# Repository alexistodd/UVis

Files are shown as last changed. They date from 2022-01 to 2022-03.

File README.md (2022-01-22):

# UV Shield 
## README

UV Shield is a handheld component that allows users to see incoming UV rays on their skin. 
The purpose of the component is to assist users with applying UV protection before going outdoors.

## OPERATION PROCEDURES
To operate the UV Shield component follow these step by step instructions:
1. Press the power button
2. Device should automatically boot up and display the UV Shield logo.
3. After the logo, UV Shield should bootup to display the camera feed.
4. Use the second button to toggle the UV LEDs when indoors.
5. Press the power button to initiate the shutdown process to safely shutdown the UV Shield.

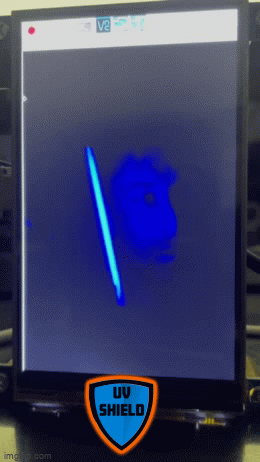
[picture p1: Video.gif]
screen-gif


## CONTACT

stevenamberman@ufl.edu

## GIT

The github repository for this project can be found at:
  https://github.com/alexistodd/UVis

## DISCLAIMER

UVis does not guarentee your safety from harmful UV rays when going outside. This component will assist you with sunscreen application,
but it does not guarentee safety from UV radiation.

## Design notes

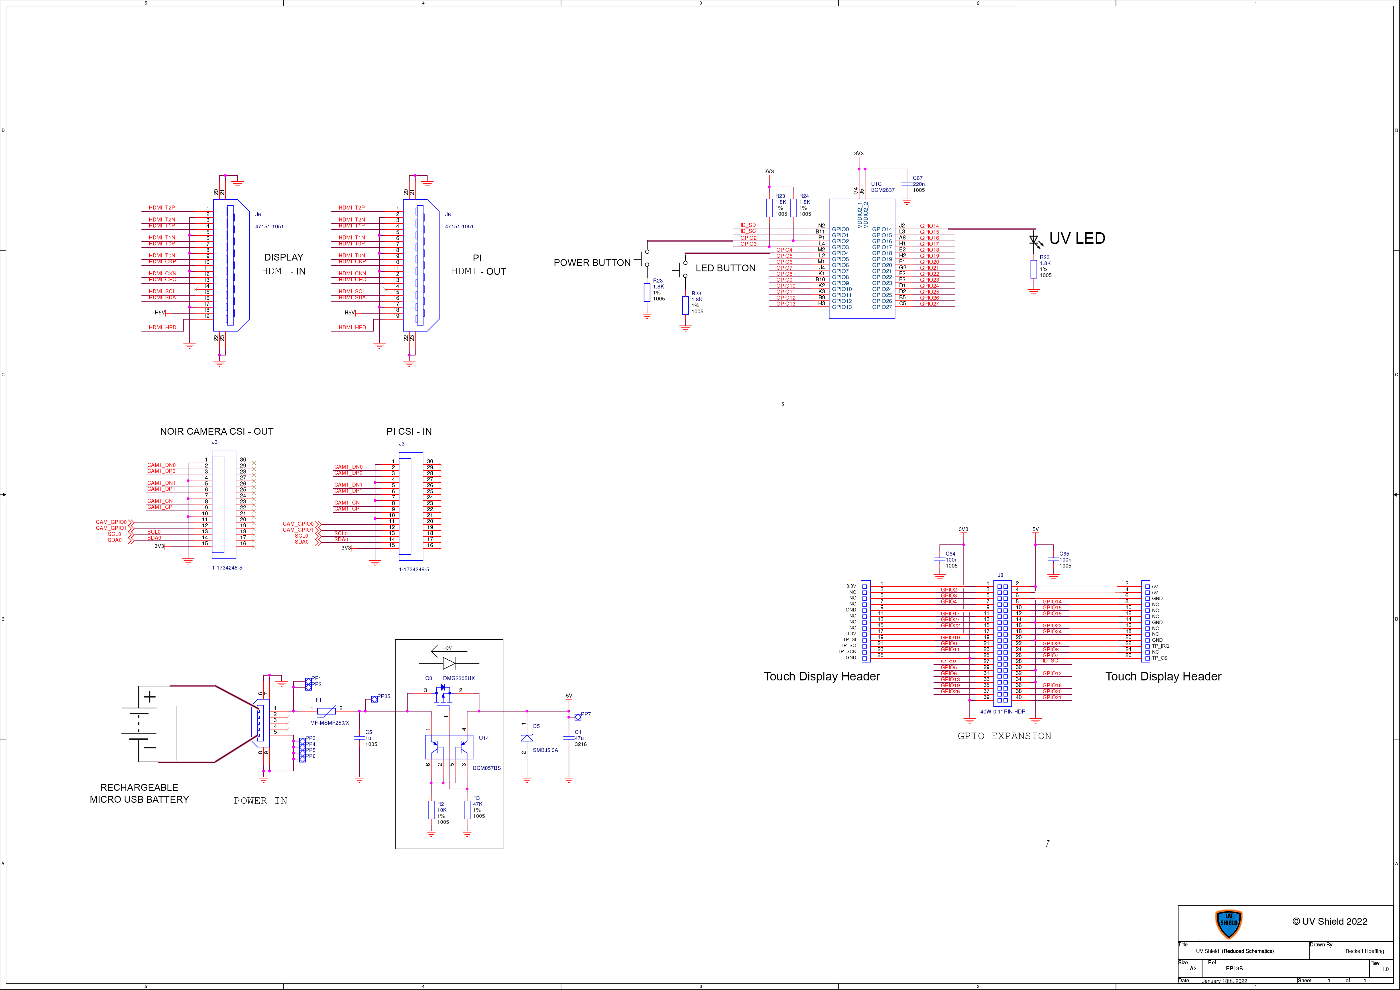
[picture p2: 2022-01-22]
Documentation/UV schematic.png

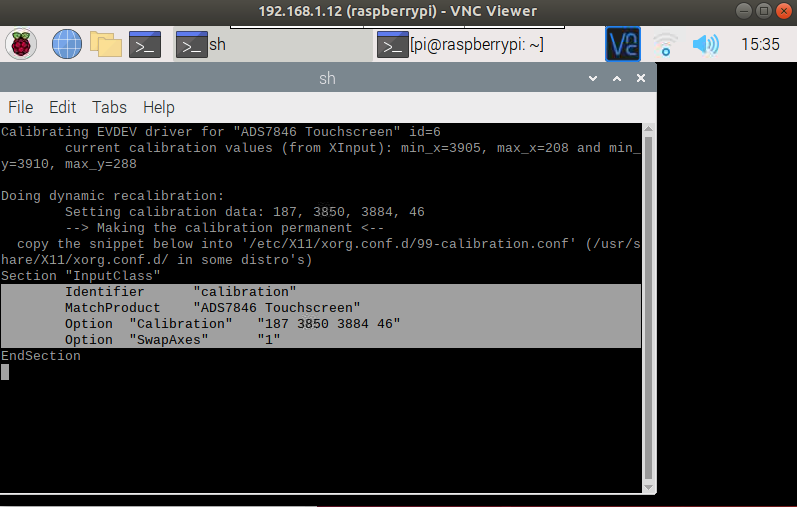
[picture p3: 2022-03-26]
PI code/touch_screen_settings.png

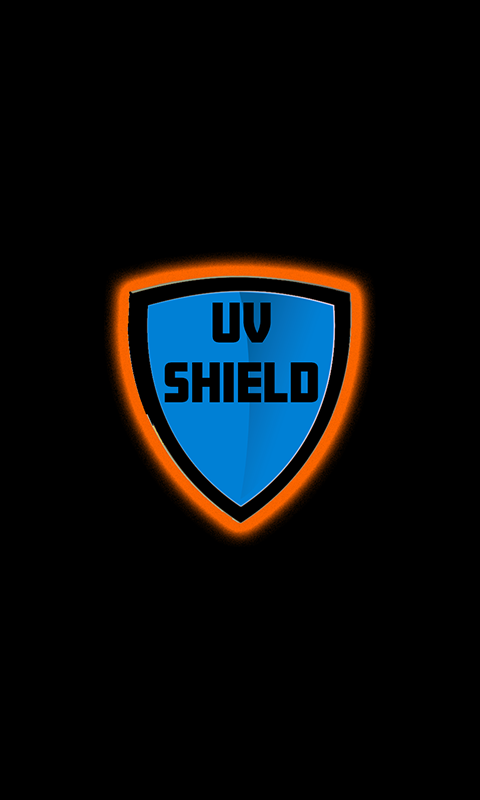
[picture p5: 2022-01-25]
Logo/Startup Screen.png

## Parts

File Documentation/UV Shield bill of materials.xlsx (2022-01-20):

Bill of Materials
Description | Quantity | Price/Part | Part Number | Source
Raspberry Pi 3 Model B | 1 | $35.00 | 1690-1000-ND | https://www.digikey.com/en/products/detail/raspberry-pi/RASPBERRY-PI-3/6152799
4 inch HDMI LCD IPS Display 800x400 | 1 | $39.99 | B07P5H2315 | https://www.amazon.com/HDMI-LCD-Resolution-Resistive-Screen/dp/B07P5H2315
Raspberry Pi NoIR camera board V2 - 8 megapixels | 1 | $29.95 | RPI3-NOIR-V2 | https://www.adafruit.com/product/3100?src=raspberrypi
Pisugar S Pro Portable 5000 mAh UPS Lithium Battery | 1 | 30.99 | B09J3WS695 | https://www.amazon.com/Portable-Platform-Raspberry-Accessories-handhold/dp/B097RCFHD2?s=electronics
Cherry MX Switches | 2 | $0.70 | B09M2K8K5P | https://www.amazon.com/Switches-Replaceable-Equivalent-Mechanical-Keyboard/dp/B09M2K8K5P
EDGELEC 12 Volt 5mm UV LED Lights | 2 | $0.28 | PW-DIP LED | https://www.amazon.com/dp/B07T9L612N?ref=ppx_yo2_dt_b_product_details&th=1
UV Pass Glass Filter | 1 | $28.00 | ROFPCUVP22 | https://www.bhphotovideo.com/c/product/1010867-REG/rosco_120336607508_2x2_permacolor_glass_filter.html
 | Total: | $165.89

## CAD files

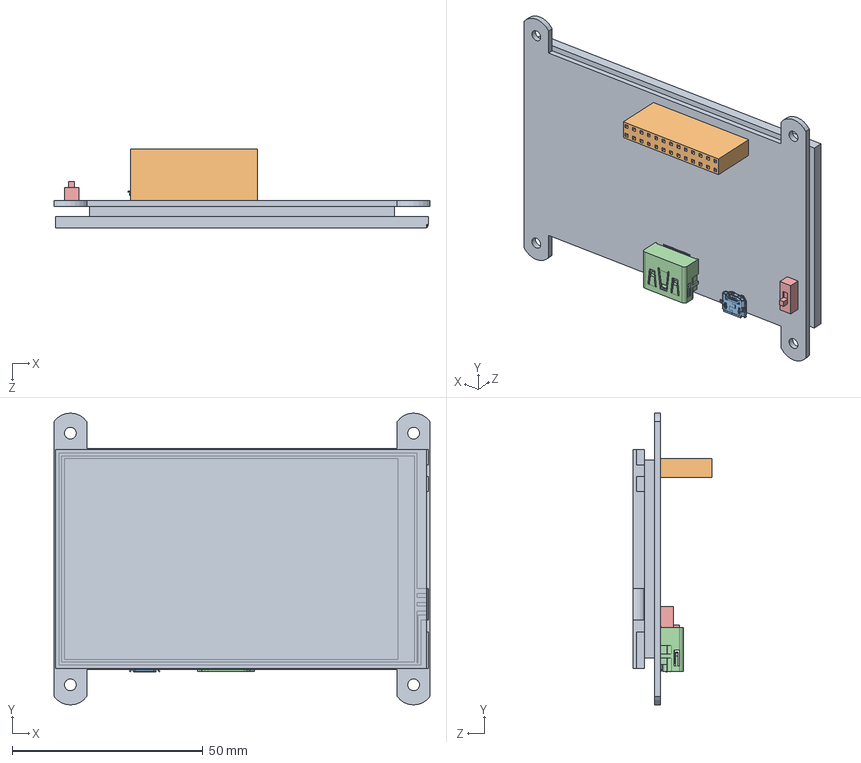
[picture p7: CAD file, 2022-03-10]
3D printing/Assembly/User_Library-4inch_HDMI_LCD/User Library-4inch HDMI LCD.sldasm
98.6 x 76.5 x 20.8 mm
User Library-4inch HDMI LCD_4inch HDMI LCD
User Library-4inch HDMI LCD_Conector hembra 13ppp
User Library-4inch HDMI LCD_Conector microUSB
User Library-4inch HDMI LCD_Conector USB
User Library-4inch HDMI LCD_switch

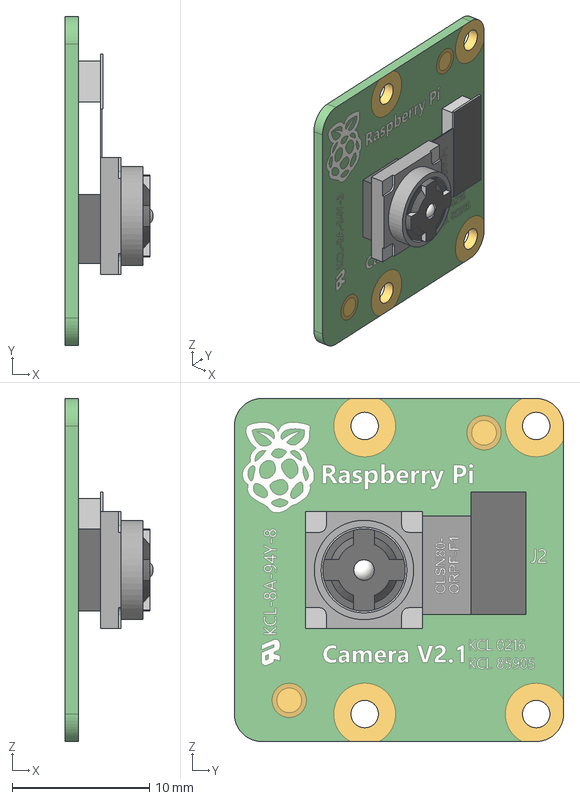
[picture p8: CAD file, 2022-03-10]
3D printing/Assembly/raspberry-pi-camera-4.snapshot.1/Raspberry pi 3 cam V2,1/Cam V2.1 v1.step
6.45 x 24.0 x 25.0 mm

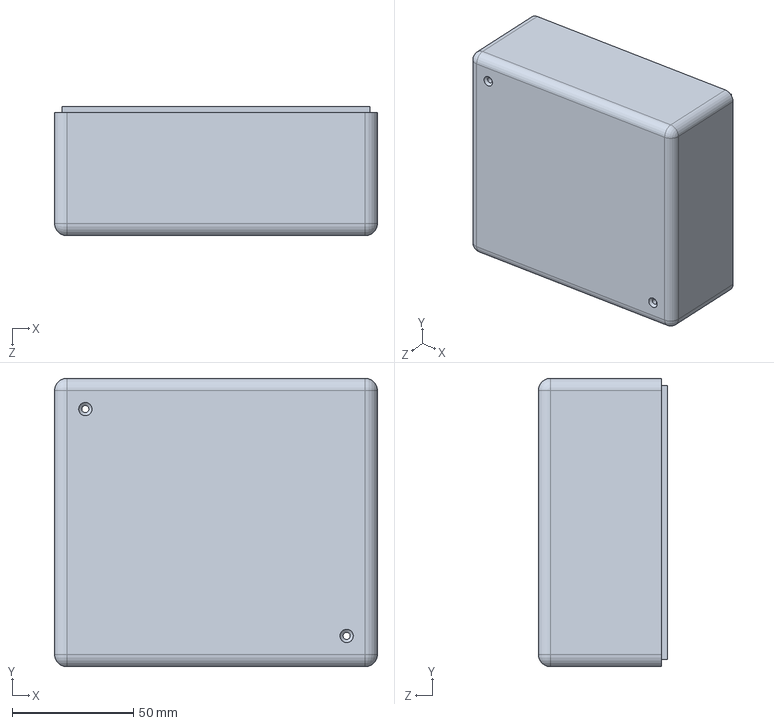
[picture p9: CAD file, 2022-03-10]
3D printing/Assembly/Uvis_Back_Case_Design_Rev_2.3.SLDPRT
133.1 x 118.9 x 53.3 mm

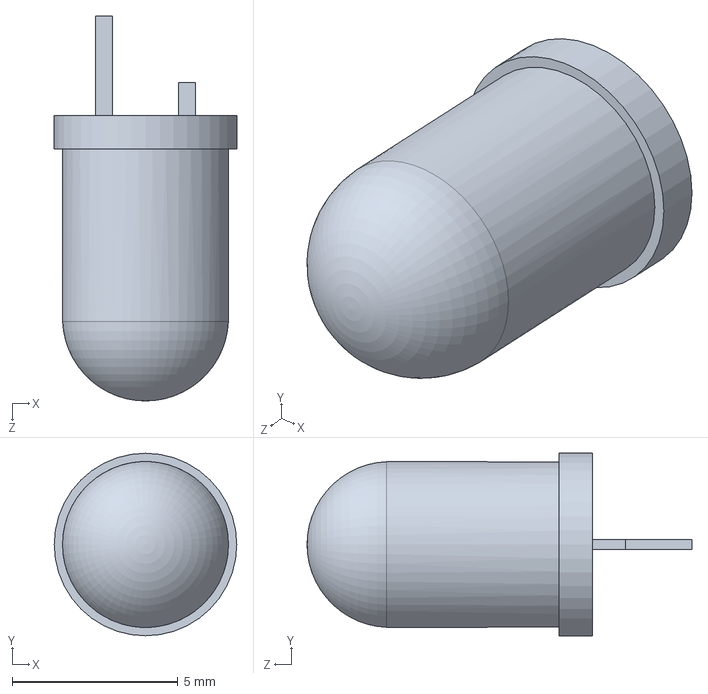
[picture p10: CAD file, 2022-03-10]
3D printing/Assembly/5mmLEDBlue.SLDPRT
5.50 x 5.50 x 11.6 mm

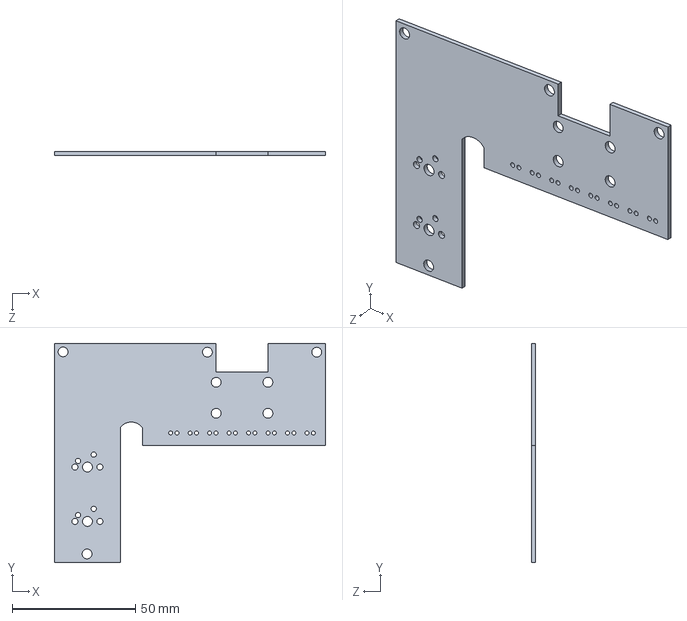
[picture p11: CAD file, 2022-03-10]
3D printing/Assembly/pcb.SLDPRT
109.8 x 88.8 x 1.60 mm

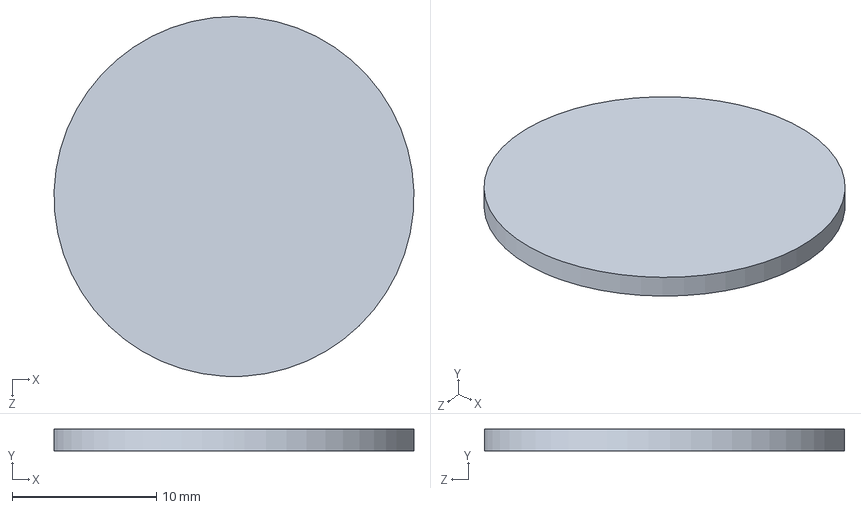
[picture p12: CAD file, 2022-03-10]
3D printing/Assembly/Filter.SLDPRT
25.0 x 1.50 x 25.0 mm

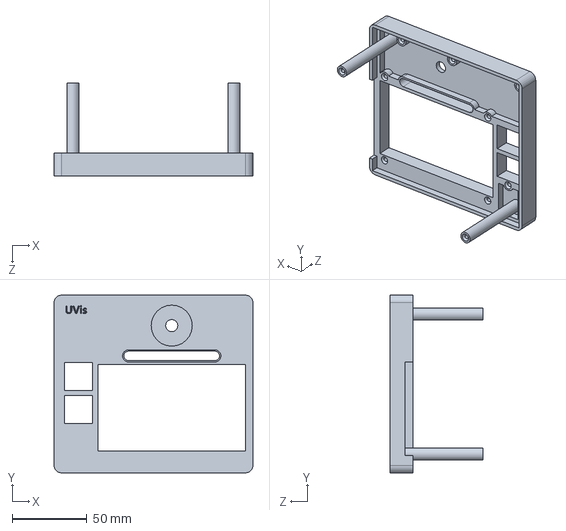
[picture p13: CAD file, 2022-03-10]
3D printing/Assembly/Uvis_Case_Design_Rev2.3.SLDPRT
133.1 x 118.9 x 62.2 mm

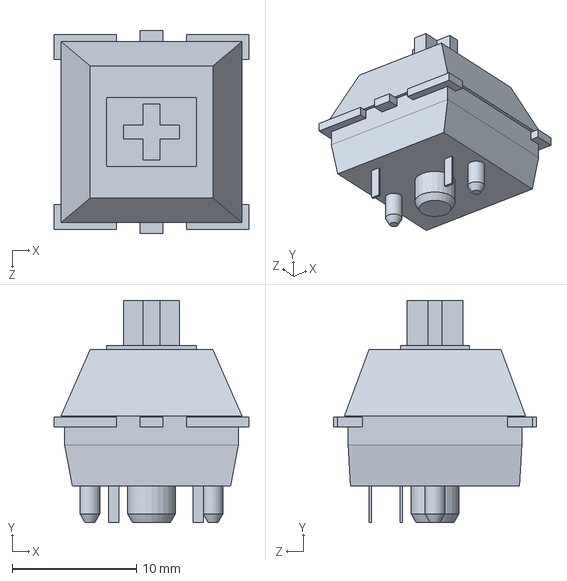
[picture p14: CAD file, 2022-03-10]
3D printing/Assembly/cherry mx.SLDPRT
15.6 x 17.9 x 16.3 mm

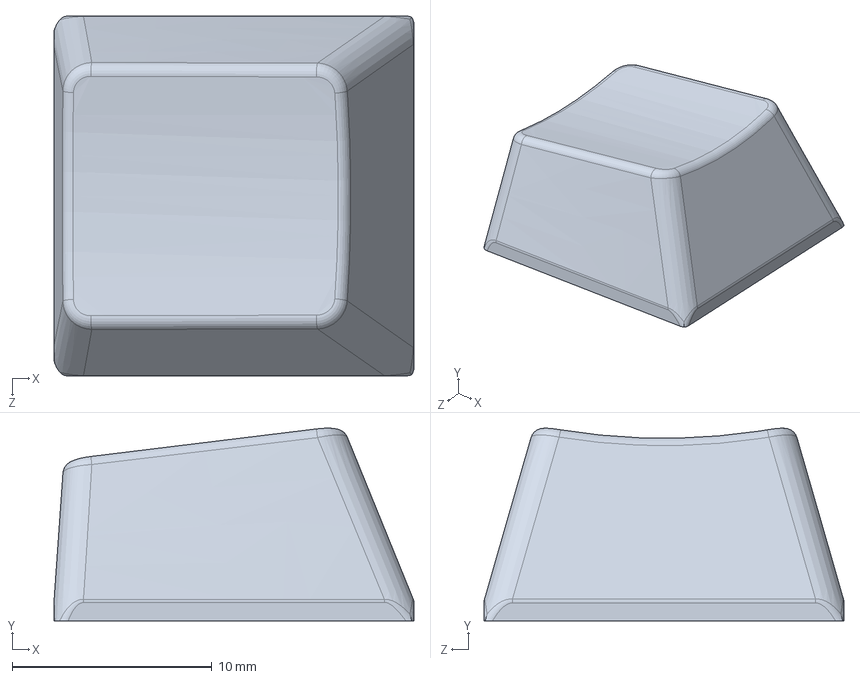
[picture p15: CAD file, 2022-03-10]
3D printing/Assembly/Cherry MX Keycap.SLDPRT
18.0 x 9.64 x 18.0 mm

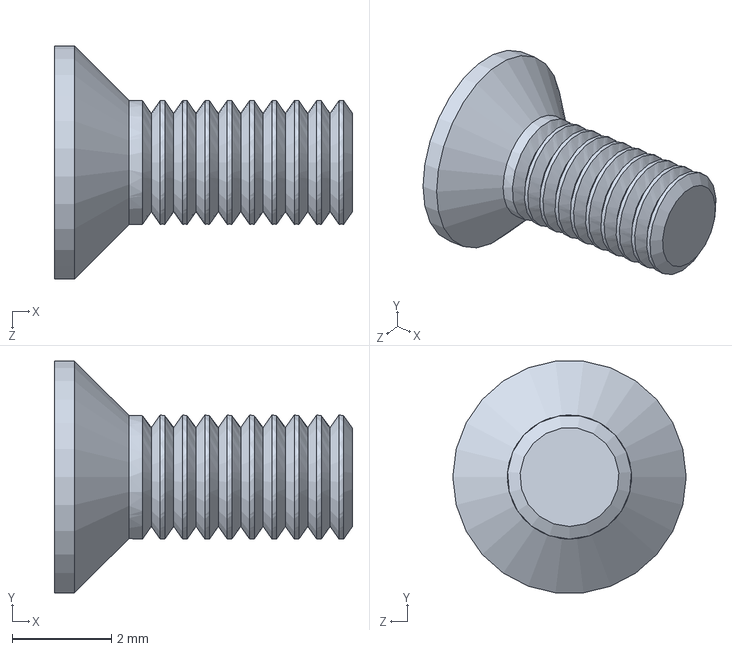
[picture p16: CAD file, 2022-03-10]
3D printing/Assembly/M2.5 Screw.SLDPRT
6.00 x 4.67 x 4.70 mm

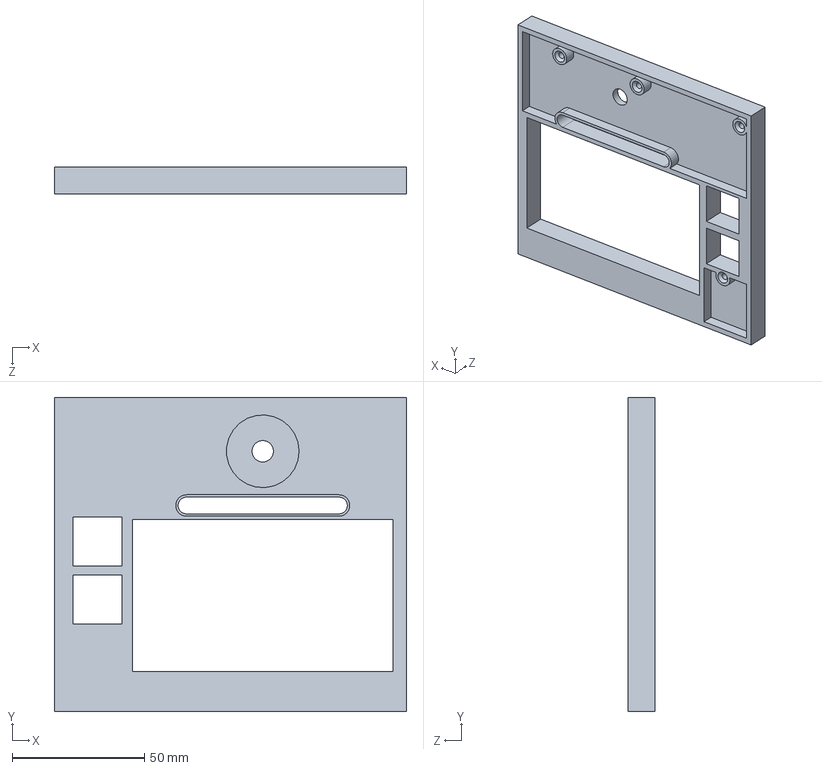
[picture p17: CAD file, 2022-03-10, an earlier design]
3D printing/Assembly/Uvis_Case_Design_Rev2.2.SLDPRT
133.1 x 118.9 x 10.2 mm

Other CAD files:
3D printing/Assembly/User_Library-4inch_HDMI_LCD/User Library-4inch HDMI LCD_Conector USB.sldprt
3D printing/Part1.SLDPRT
3D printing/Assembly/User_Library-4inch_HDMI_LCD/User Library-4inch HDMI LCD_Conector microUSB.sldprt
3D printing/Assembly/User_Library-4inch_HDMI_LCD/User Library-4inch HDMI LCD_switch.sldprt
3D printing/Assembly/User_Library-4inch_HDMI_LCD/User Library-4inch HDMI LCD_Conector hembra 13ppp.sldprt
3D printing/Assembly/User_Library-4inch_HDMI_LCD/User Library-4inch HDMI LCD_4inch HDMI LCD.sldprt

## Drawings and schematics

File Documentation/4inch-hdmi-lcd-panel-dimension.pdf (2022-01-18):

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

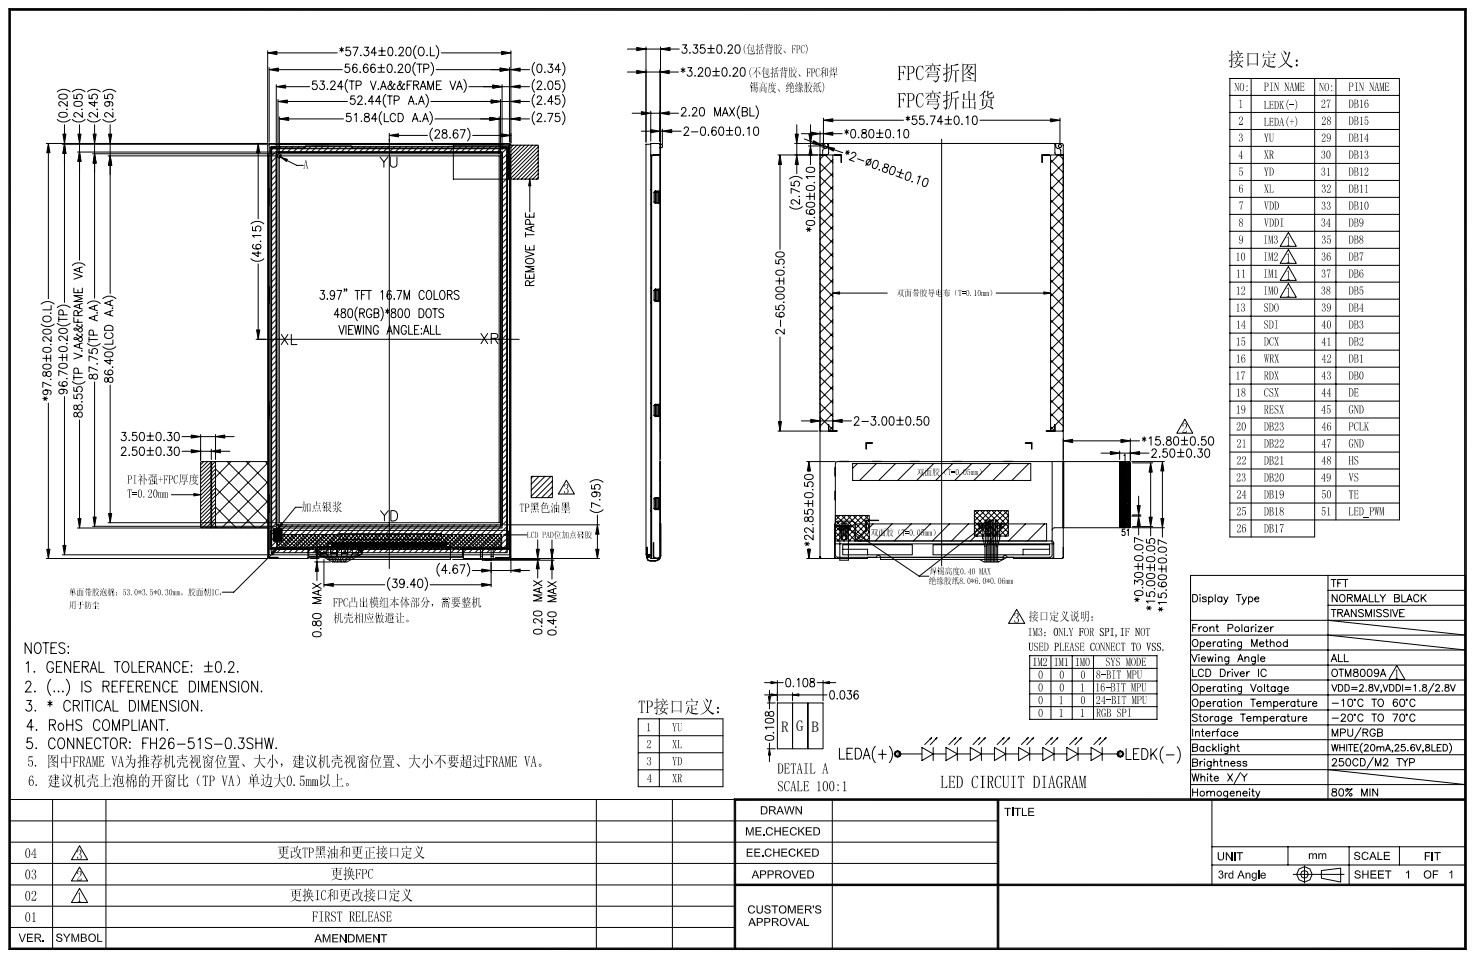
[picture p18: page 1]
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

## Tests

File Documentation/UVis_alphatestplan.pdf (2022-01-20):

University of Florida | CEN3907: Computer Engineering Design 2 | UVis
ECE Department | Alpha Test Plan | 1/20/2022

# Alpha Test Plan

Introduction

This document will explain how UVis will design and test the UV Shield component over the course of the semester. We will provide the expected behaviors for the component when it is being used, as well as some testing procedures to make sure these behaviors are performing as designed.

Specification

Expected Behaviors
1. Power button allows a user to turn the device on and off.
2. When the device is powered on, it will automatically boot up to our logo design (the UVShield), and then to the application.
3. The application consists of the camera feed displayed in full screen on the LCD screen.
4. A tactile switch will allow the user to power low radiation UV LEDs.
5. Device should run for a usable amount of time (more than 1 hour) off battery power.

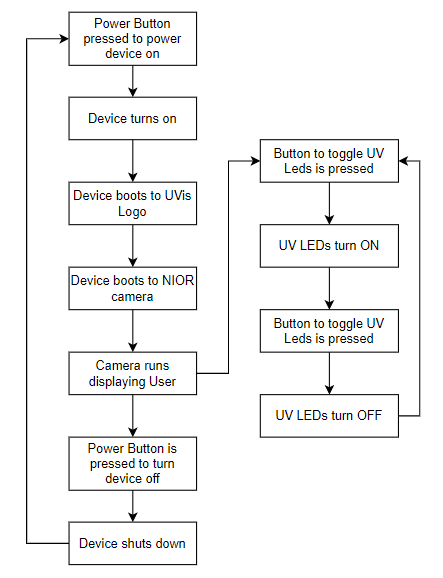
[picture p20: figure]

Figure 1: Flowchart explaining the device’s expected behaviors

University of Florida | CEN3907: Computer Engineering Design 2 | UVis
ECE Department | Alpha Test Plan | 1/20/2022

Test Procedures

Hardware | Software
- Verify device turns on when power button is pressed. - Measure power draw of the device to make sure the battery life is sufficient (more than 1 hour) - Verify the LED toggle button provides the correct signal back to the GPIO headers when pressed. - Verify the GPIO headers send the correct outputs to the UV LEDs based on the button input. - Use libcam to verify the camera turns on - Verify that the device turns back off properly when the power button is again pressed. | - Display the UVis logo upon bootup. - After the logo is displayed, verify the component boots into the camera application. - Verify the shutdown process occurs when the power button is pressed to allow for safe shutdown.

Conclusion
Overall, the UV Shield component is straightforward and easy to use. Based on this document any user should be able understand how the device operates by reading the expected behaviors section and looking at the flowchart. In addition, outside testers should be able to look through the test procedures the assist them with verifying that the device performs as intended.

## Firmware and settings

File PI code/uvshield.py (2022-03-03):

# Start the camera when the pi turns on in fullscreen mode with width
# and height that matches the LCD Display
#import os

#os.system('libcamera-vid -t 10000 --fullscreen --width 800 --height 480')

# Button input
import RPi.GPIO as GPIO
from time import sleep
GPIO.setmode(GPIO.BCM)

# sleeptimer
sleepTime = 0.1

# LED light pins
lightPin1 = 16
lightPin2 = 12

# Light button pins
lightButton = 20
powerPin = 21

# Set the pins to inputs or outputs 
GPIO.setup(lightPin1, GPIO.OUT)
GPIO.setup(lightPin2, GPIO.OUT)
GPIO.setup(lightButton, GPIO.IN)#, pull_up_down=GPIO.PUD_UP) # set to pull up
GPIO.setup(powerPin, GPIO.OUT)

GPIO.output(powerPin, 1)
GPIO.output(lightPin1, 0)
GPIO.output(lightPin2, 0)

lightOn = False

while True:
    if(GPIO.input(lightButton) == 1):
        if(lightOn == True):            
            GPIO.output(lightPin1, 0)
            GPIO.output(lightPin2, 0)
            while(lightButton == True):
                sleep(sleepTime)
            lightOn = False
        else:
            GPIO.output(lightPin1, 1)
            GPIO.output(lightPin2, 1)
            while(lightButton == True):
                sleep(sleepTime)
            lightOn = True
#     GPIO.output(lightPin1, GPIO.input(lightButton))
#     GPIO.output(lightPin2, GPIO.input(lightButton))
    sleep(sleepTime)
    
    

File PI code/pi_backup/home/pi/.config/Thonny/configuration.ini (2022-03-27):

[general]
configuration_creation_timestamp = 2022-03-27T14:28:40.985740

[view]
full_screen = False
maximize_view = False
shellview.visible = True
show_program_arguments = False
show_plotter = False
assistantview.visible = False
astview.visible = False
stackview.visible = False
exceptionview.visible = False
filesview.visible = False
heapview.visible = False
helpview.visible = False
notesview.visible = False
objectinspector.visible = False
outlineview.visible = False
variablesview.visible = False

[file]
recent_files = ['/home/pi/Desktop/camera/click.py', '/home/pi/Desktop/camera/camera_transparent.py']
current_file = /home/pi/Desktop/camera/click.py
open_files = ['/home/pi/Desktop/camera/click.py']

[layout]
zoomed = False
notebook_nw_visible_view = None
notebook_w_visible_view = None
notebook_sw_visible_view = None
notebook_s_visible_view = ShellView
notebook_ne_visible_view = None
notebook_e_visible_view = None
notebook_se_visible_view = None
width = 640
height = 480
left = 36
top = 16
west_pw_width = 200
east_pw_width = 200
nw_nb_height = 200
sw_nb_height = 200
s_nb_height = 200
se_nb_height = 200
ne_nb_height = 200

[run]
program_arguments = 
dock_user_windows = False
pgzero_mode = False
working_directory = /home/pi/Desktop/camera

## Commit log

2022-03-10 Adding files for Case 2.0
    Adding files worked on for Case with PCB integration.
    [5mmLEDBlue.SLDPRT, Cam V2.1 v1.step, Cherry MX Keycap.SLDPRT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]
2022-03-22 Create Raspberry OS Installation
2022-03-22 Update Raspberry OS Installation
2022-03-22 Adding Small Change to case for kolari uv filter
    Still needs to be finished, but it is prepped for adding the kolari uv filter screw threads
2022-03-26 touch screen calibration code
2022-03-27 Create Python camera app
2022-03-27 Update Python camera app
